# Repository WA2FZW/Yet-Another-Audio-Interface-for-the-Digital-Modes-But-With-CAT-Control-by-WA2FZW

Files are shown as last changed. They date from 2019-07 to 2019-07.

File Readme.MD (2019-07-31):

Yet Another Audio Interface for the Digital Modes (But With CAT Control)
Version 2.0 by John Price – WA2FZW

A while back, my primary radio went belly up, and while it was out for
repairs, I thought I might drag out my old Swan-250C 6 meter rig so I
could at least get on the air. I had built a simple hand-wired audio
interface for it, but couldn’t find it, so I designed a new one!

The audio portion of the device is pretty standard. It is a hybrid of
the “Easy Digi” audio interface and a few other designs that are
floating around. What’s different about this one is that I added an
Arduino Nano processor so that the transmitter could be keyed via CAT
control instead of using the more common RS-232 hack.

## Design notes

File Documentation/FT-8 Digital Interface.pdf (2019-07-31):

- Page 1 -

## Yet Another Audio Interface for the Digital Modes (But With CAT Control) Version 2.0 John Price – WA2FZW

## Introduction

A while back, my primary radio went belly up, and while it was out for repairs, I thought I might drag out my old Swan-250C 6 meter rig so I could at least get on the air. I had built a simple hand-wired audio interface for it, but couldn’t find it, so I designed a new one!

The audio portion of the device is pretty standard. It is a hybrid of the “Easy Digi” (https://forums.qrz.com/index.php) audio interface and a few other designs that are floating around. What’s different about this one is that I added an Arduino Nano processor so that the transmitter could be keyed via CAT control instead of using the more common RS-232 hack.

## Changes in Version 2.0

In Version 2.0 I replaced the entire message handling code that was in the original versions with a standard Arduino library which I had developed for another project. That library can be downloaded from GitHub (https://github.com/WA2FZW/An-FT-891-CAT-Control-Emulator-Library-by-WA2FZW) and installed in your Arduino library directory.

## Hardware

The audio portion of the hardware is similar to other audio interfaces commonly available. Here’s the full schematic:

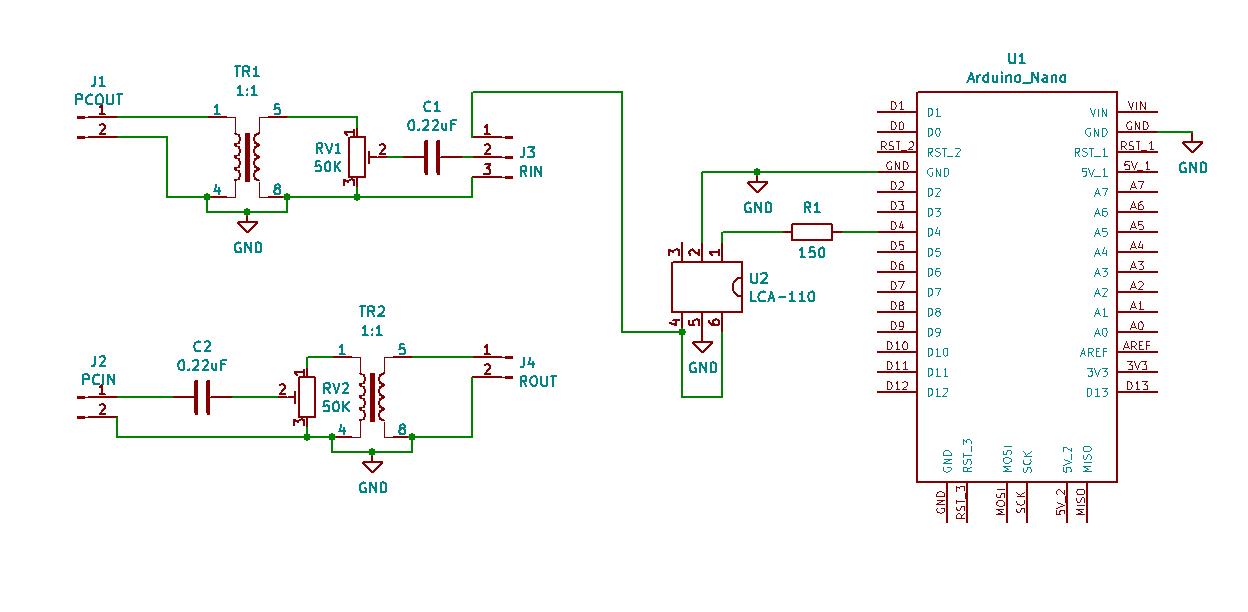
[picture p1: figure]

- Page 2 -

Transformer isolation is used for both the transmit and receive audio paths and C1 and C2 block any DC on the microphone connections; the PC microphone is set up for an electret type microphone and thus there is a DC bias present. The same is true for my BitX-40 radio as well.

RV1 & RV2 provide a means of setting the audio levels such that they can be more finely adjusted using the PC’s control panel settings and/or by the program that is interfaced to the radio. The schematic shows these to both be 50KΩ trimpots (what I happened to have in the parts bin), but almost any value will probably work.

When you install RV1 and RV2 on the PCB, you want to orient them so that the resistance between the ground pin and the center pin increases as you turn the adjustment clockwise.

The Arduino operates U2, which is a common solid state relay to key the transceiver’s PTT line when it receives a command to transmit or receive from the PC via its built-in USB port.

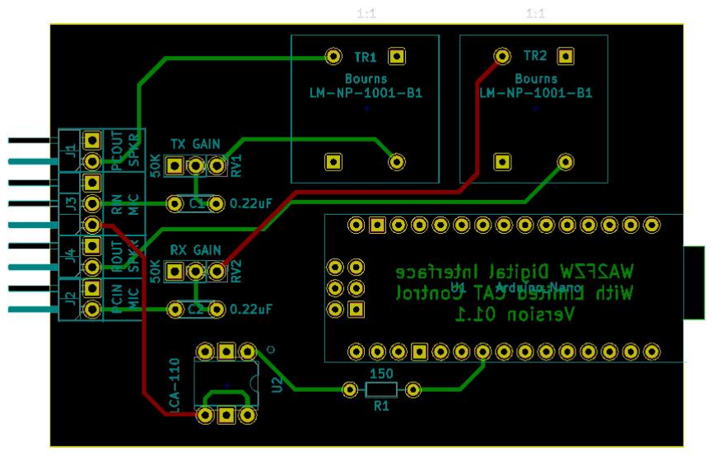
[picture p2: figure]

- Page 3 -

Here’s the circuit board (the Gerbers are included in the distribution package):

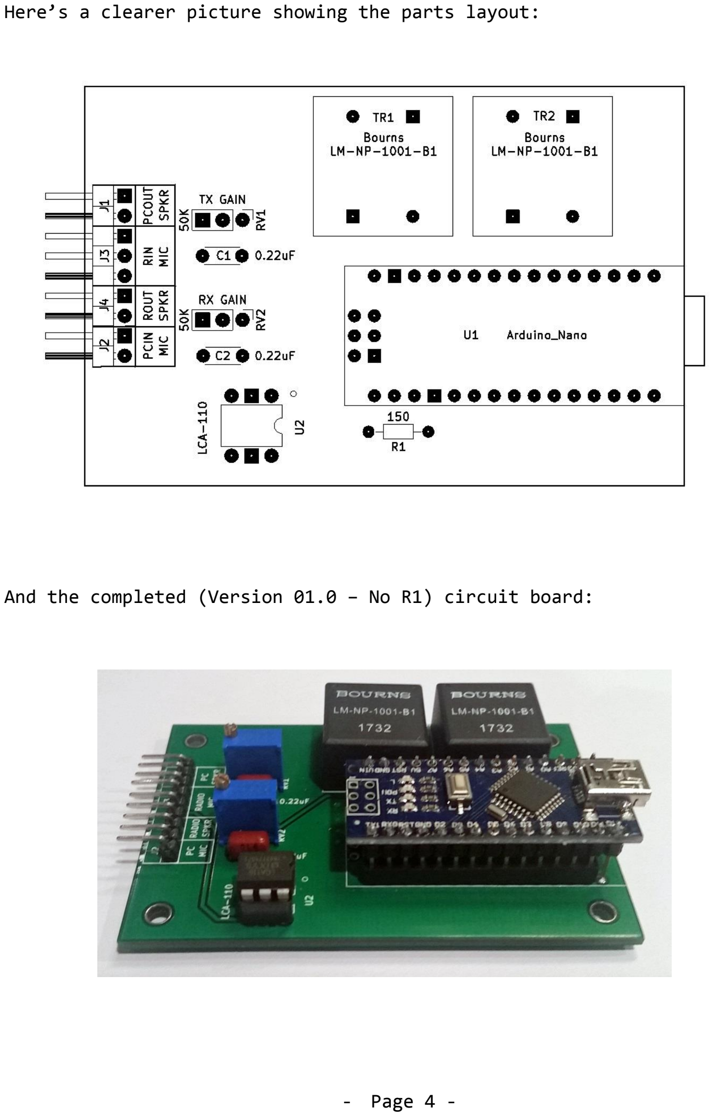
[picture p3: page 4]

- Page 4 -

Here’s a clearer picture showing the parts layout:

And the completed (Version 01.0 – No R1) circuit board:

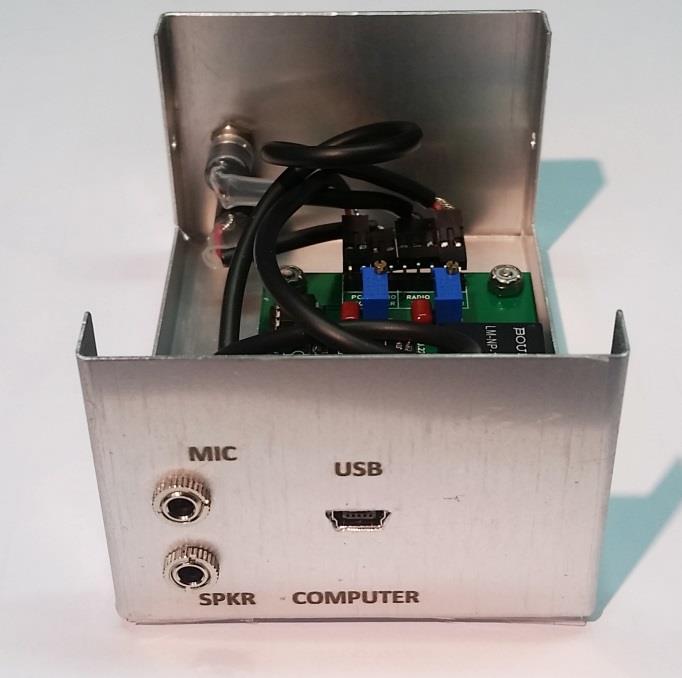
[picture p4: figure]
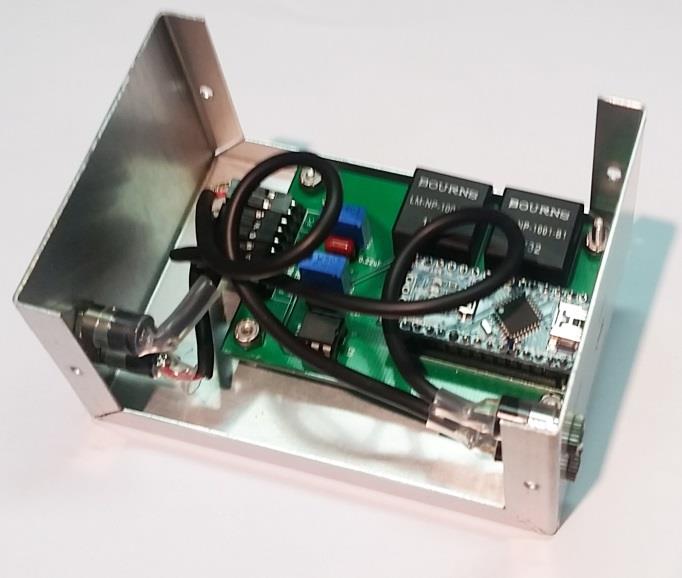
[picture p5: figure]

- Page 5 -

I used a standard 28 pin IC socket for the Nano, even though it has 30 pins. As D12 and D13 are not used (the 2 end pins on the end of the board with the USB connector) they don’t go in the socket. If you look closely at the picture above, you can see that.

Update: I finally put it in a box; here’s what that looks like:

## Software

The software is a pretty “dumb” CAT control program. It uses the Yaesu FT-891 command language. (http://www.yaesu.com/airband/indexVS.cfm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) Why did I choose that instead of the more common Kenwood language? My primary radio is an FT-891 and my primary CAT control program is DxCommander. When I first got the radio, there were a number of issues with how the two communicated due to some things I consider bugs in the radio’s software and some misconceptions that the author of DxCommander had about the radio’s command language (he didn’t have one to test with). The author and I spend several weeks working out the kinks, so I know this code will work with DxCommander. It should also work with other CAT controllers capable of communicating with the FT-891 such as N1MM+. (https://n1mm.hamdocs.com/tiki-index.php)

- Page 6 -

Program File

In Version 2.0, there is only one file; Digital_Ifc_V2.0.ino. As noted earlier, all of the actual CAT control message handling is now done in the FT891_CAT library available on GitHub. (https://github.com/WA2FZW/An-FT-891-CAT-Control-Emulator-Library-by-WA2FZW)

Operational Overview

As I stated earlier, this is a pretty “dumb” program. It only responds intelligently to two messages; “TX” and “ID”. When it receives an “ID” message, it responds with “ID0650;” indicating the CAT language in use is that for the FT-891. “TX1;” and “TX0;” messages tell the Arduino to turn the transmitter on or off.

Commands to change parameters in the “radio” simply update the values of various things such as frequencies and operating modes stored in the library. Status requests for these items are answered based on those stored values. This keeps the controlling PC program happy as not getting a response to a request might cause problems.

Program Functions

The following sections provide a high level description of what each function in the program does. More detailed information can be found in the comments in the files themselves.

The functions are listed in the order in which they appear in the program.

setup

This function assigns the Arduino pins used to control the transmitter and on-board LED, starts the serial communications channel and and initializes the FT891_CAT library.

loop

Once the setup function completes, loop runs forever.

- Page 7 -

It calls CAT.CheckCAT() in an if statement. If that function returns a true indication, it means that a new command was received and processed by the library and that we should go look to see what changed. If it returns false, then nothing changed.

If a new command was processed, we call CAT.GetTX() in an if statement to get the current transmit/receive status and turn the Arduino’s on-board LED on or off as appropriate; note, the CAT library will turn the transmitter on or off, so this program doesn’t need to handle that task.

Delay

This is a non-blocking time waster. The standard Arduino “delay” function blocks interrupts, which prevents I/O from happening.

## Setting the Audio Levels

The two trimpots (RV1 & RV2) are used to adjust the audio levels between the real radio and the PC. There are several adjustments that can affect the levels:

- The trimpots
- The Windows (or other OS) audio level controls (in the Control Panel) under “Sound”.
- The audio output level adjustment and mic gain adjustments for the radio itself.
- The “Power” adjustment on the WSJT-X main screen

As we’re dealing with old-fashioned radios here, there may be no microphone gain adjustment, and the only adjustment for the output level may be the volume control (unless you go into the radio and pick off an audio signal before the volume control).

To the extent possible set the audio controls on the radio to mid-range values or for the audio output, a comfortable listening level. Similarly, set the PC level controls and DxCommander “Power” controls to mid-range values.

- Page 8 -

With the radio just receiving noise, adjust the “RX Gain” trimpot so that the receive level meter on DxCommander shows about 40dB. If you can’t adjust it to that level, you’ll need to diddle with the PC’s microphone level adjustment or the volume setting on the radio.

If your radio has a way of displaying the ALC level, with the radio transmitting on one of the digital modes, adjust the “TX Gain” trimpot so that it just starts to show the ALC kicking in then back it off a tad.

If you can’t monitor the ALC, adjust the “TX Gain” trim pot for full power output then back it off a tad.

If you can’t get the transmit level to adjust with the trimpot you’ll need to adjust the PC’s audio output level.

## Bill of Materials

Here’s what you need to build it.

U1 | Arduino Nano Processor (socket optional)
U2 | SCA-110 Solid State Relay (socket optional)
TR1 & TR2 | Bourns LM-NP-1001-B1 Transformer (https://www.digikey.com/products/en?keywords=LM-NP-1001-B1%20)
C1 & C2 | 0.22uF capacitor
R1 | 150Ω ¼ watt resistor
J1 – J4 | Male right angle 2.54mm pin headers (the board is designed so that a single 9 pin header can be used).
RV1 & RV2 | Vertical style trimpots. (https://www.digikey.com/product-detail/en/bourns-inc/PV36W503C01B00/490-2889-ND/666516) The schematic calls for 50KΩ since I had a bunch on hand, but most likely almost any value greater than 2KΩ should work just fine

J1A, J2A & J4A (Not shown on the schematic) 1/8” TS (mono type)
| audio jacks mounted on the enclosure and connected to J1, J2 and J4 respectively.

- Page 9 -
J3A | (Not shown on the schematic) 1/8” TRS (stereo type) audio jack mounted on the enclosure and connected to J3.
Enclosure | At least 4” long x 2.25” wide x 1.5” high. The one I used came from Jameco. (https://www.jameco.com/webapp/wcs/stores/servlet/ProductDisplay?productId=11870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)
Cables | Whatever you need to connect between the device and your PC and radio.

## Suggestion Box

I welcome any suggestions for further improvements. Please feel free to email me at WA2FZW@ARRL.net.

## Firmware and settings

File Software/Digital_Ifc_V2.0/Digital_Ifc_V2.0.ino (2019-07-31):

/*
 *	Digital_Ifc_V01.2
 *
 *	This is a very dumb CAT control program designed to run on an Arduino Nano for
 *	my homebrew audio interface board for using digital modes on my old Swan-250C
 *	transceiver. I use it in conjunction with the DxCommander program which I use for
 *	the digital modes, however is should work with any CAT controller capable of using
 *	the Yaesu FT-891 command set.
 *
 *	I designed it for the Yaesu FT-891 command language as that is my primary radio and
 *	the message handling code was lifted from another project related to CAT control
 *	for that radio.
 *
 *	I call it a "dumb" CAT control program in that although it will respond correctly
 *	to any command or status request sent by DxCommander (or some other program), it
 *	doesn't really do anything with any of those messages other than the "TX" message,
 *	which will key (or un-key) the transmitter.
 *
 *	Commands from the controller program simply set values in memory for the various
 *	parameters and status requests for those values are replied to based on what is in
 *	the program's memory.
 */

#include <FT891_CAT.h>			// From: https://github.com/WA2FZW/An-FT-891-CAT-Control-Emulator-Library-by-WA2FZW

#define	BIT_RATE	115200		// Baud setting for the USB port


/*
 *	The only pins used are D4, which keys the transmitter PTT line via a solid
 *	state relay and D13 which turns the LED on the Arduino board on or off.	
 */

#define	PTT_PIN	 4				// Push-to-talk line
#define	LED_PIN	13				// The Arduino's built in LED


/*
 *	These definitions are for the on/off state of the LED
 */

#define	LED_ON	HIGH			// HIGH turns the LED on
#define	LED_OFF	LOW				// So LOW must turn it off!


	FT891_CAT	CAT;			// Make CAT control object


/*
 *	"setup" initializes everything the rest of the program needs to function properly
 */

void setup ()
{

/*
 *	Set up the LED:
 */

	pinMode ( LED_PIN, OUTPUT );				// Turns the Arduino's built-in LED on or off
	digitalWrite ( LED_PIN, LED_OFF );			// Turn the LED off


/*
 *	Start the serial monitor
 */

	Serial.begin ( BIT_RATE );					// Serial monitor runs at high speed

	CAT.begin ( PTT_PIN );						// Initialize CAT control stuff
}


/*
 *	The loop processing is pretty trivial. We see if DxCommander has anything to say,
 *	and if so, we read it and process it.
 */

void loop ()
{
	if ( CAT.CheckCAT() )							// Any new commands?
	{
		if ( CAT.GetTX() )							// Transmitter on?
			digitalWrite ( LED_PIN, LED_ON );		// Light the LED

		else										// Receiving
			digitalWrite ( LED_PIN, LED_OFF );		// So turn the LED off
	}

	Delay ( 25 );								// Only check every 25mS
}


/*
 *	"Delay" is a non-blocking delay function. The standard Arduino "delay" function
 *	turns off interrupts, which prevents the Serial I/O functions from working. That
 *	sometimes causes characters to be missed and junk commands to show up.
 */

void Delay ( unsigned long interval )
{
unsigned long currentTime = 0UL;

unsigned long startTime = millis();

	while ( startTime + interval > currentTime )
    	currentTime = millis();
}
